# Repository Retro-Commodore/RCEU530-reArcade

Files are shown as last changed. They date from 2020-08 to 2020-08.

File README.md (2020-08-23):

# RCEU530-reArcade
 new Arcade PCB with autofire

reArcade is an all microswitch drop-in replacement PCB for the Arcade joystick.  
Added is the possibility of an autofire using a 555 timer.  
Microswtich in firebutton - in case you don't want to modify the original pcb.  

In order to use autofire, a new cable is required which supplies 5v.

The long arm microswitch needs to be bent 90deg, 1.6-1.7cm from where it enters the house, then +1cm from there approx 80deg. You may need to test it by trial-and-error.

# BOM
4x Microswitches with regular size arm [eBay](https://www.ebay.com/itm/10-X-KW4-3Z-3-Hinge-Roller-Lever-SPDT-Momentary-Micro-Limit-Switch-3D-printer/122688679006).  
1x Microswitch with long arm [eBay](https://www.ebay.com/itm/5Pcs-AC250-125V-5A-3P-Momentary-36mm-Lever-Arm-Micro-Switch-Green-KW12-9S/233272820914).  
1x 1x7 pin male pinheader.  
  
**Optional Autofire**  
1x on/off switch  
1x SMD 0805 Resistor 33k  
1x SMD 0805 Resistor 4k7  
2x SMD 0805 Capacitor 10nF  
1x SMD 555 timer  
1x Joystick cable with 5v (min 7 wire cable, DB9 female, 1x7 pin female connector 2.54mm - or just get a finished extension cable on ebay).  

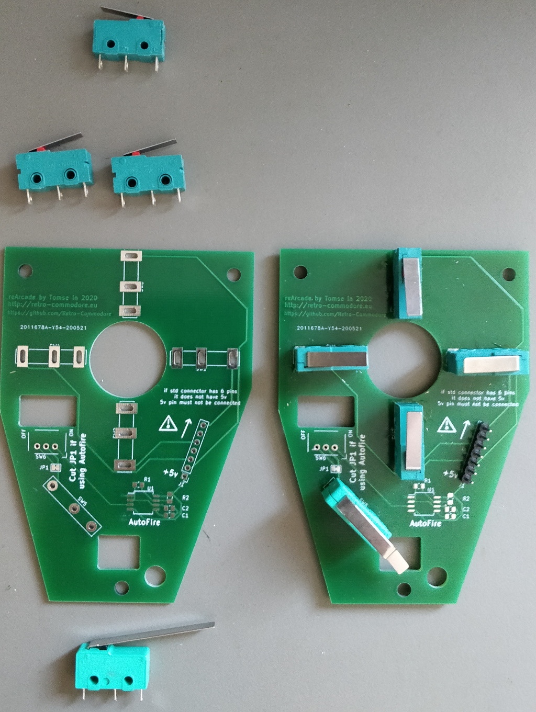
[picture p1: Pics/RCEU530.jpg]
Rendered Pic


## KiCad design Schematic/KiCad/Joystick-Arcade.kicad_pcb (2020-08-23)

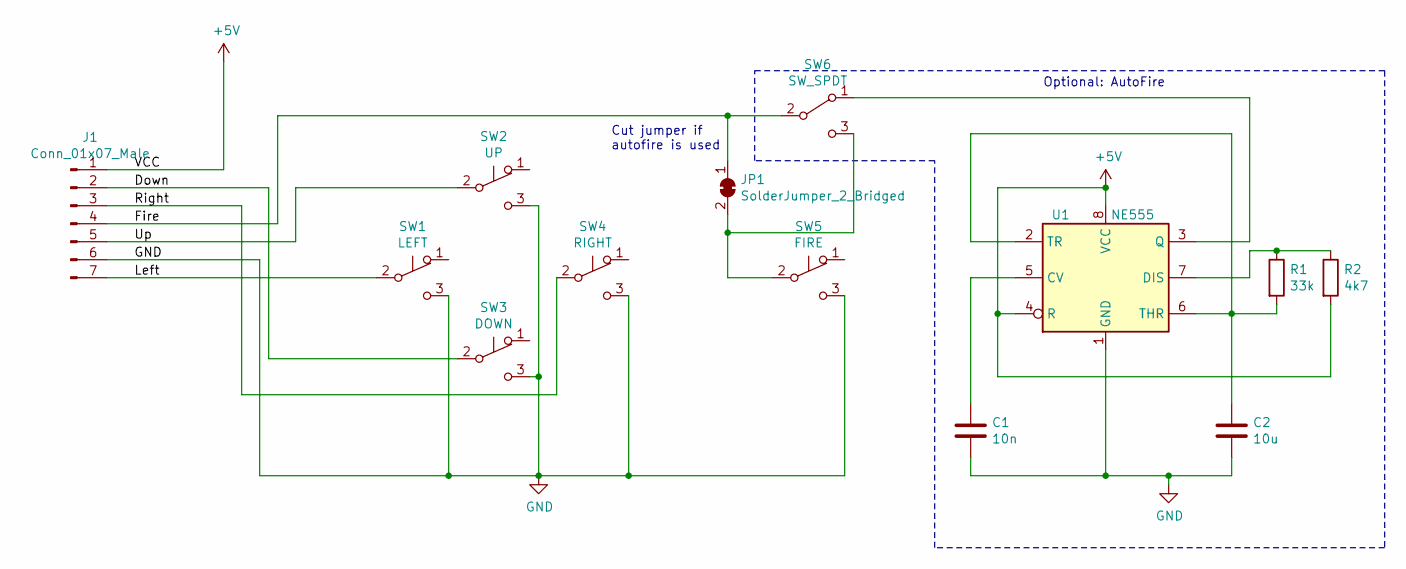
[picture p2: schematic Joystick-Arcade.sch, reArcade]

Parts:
C1: 10n; C_0805_2012Metric
C2: 10u; C_0805_2012Metric
J1: Conn_01x07_Male; PinHeader_1x07_P2.54mm_Vertical
JP1: SolderJumper_2_Bridged; SolderJumper-2_P1.3mm_Bridged_Pad1.0x1.5mm
R1: 33k; R_0805_2012Metric_Pad1.15x1.40mm_HandSolder
R2: 4k7; R_0805_2012Metric_Pad1.15x1.40mm_HandSolder
SW1: LEFT; Microswitch-no-nc-c-wire
SW2: UP; Microswitch-no-nc-c-wire
SW3: DOWN; Microswitch-no-nc-c-wire
SW4: RIGHT; Microswitch-no-nc-c-wire
SW5: FIRE; Microswitch-nc-no-c-pcb
SW6: SW_SPDT; SW_E-Switch_SS12D00G3_SPDT_Angled
U1: NE555; SO-8_5.3x6.2mm_Pitch1.27mm

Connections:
+5V: J1.1, R2.2, U1.4 (R), U1.8 (VCC)
/Down: J1.2, SW3.2 (B)
/Fire: J1.4, JP1.1 (A), SW6.2 (B)
/Left: J1.7, SW1.2 (B)
/Right: J1.3, SW4.2 (B)
/Up: J1.5, SW2.2 (B)
GND: C1.2, C2.2, J1.6, SW1.3 (C), SW2.3 (C), SW3.3 (C), SW4.3 (C), SW5.3 (C), U1.1 (GND)
unnamed: C1.1, U1.5 (CV)
unnamed: C2.1, R1.2, U1.2 (TR), U1.6 (THR)
unnamed: JP1.2 (B), SW5.2 (B), SW6.3 (C)
unnamed: R1.1, R2.1, U1.7 (DIS)
unnamed: SW6.1 (A), U1.3 (Q)

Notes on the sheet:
Optional: AutoFire
Cut jumper if autofire is used

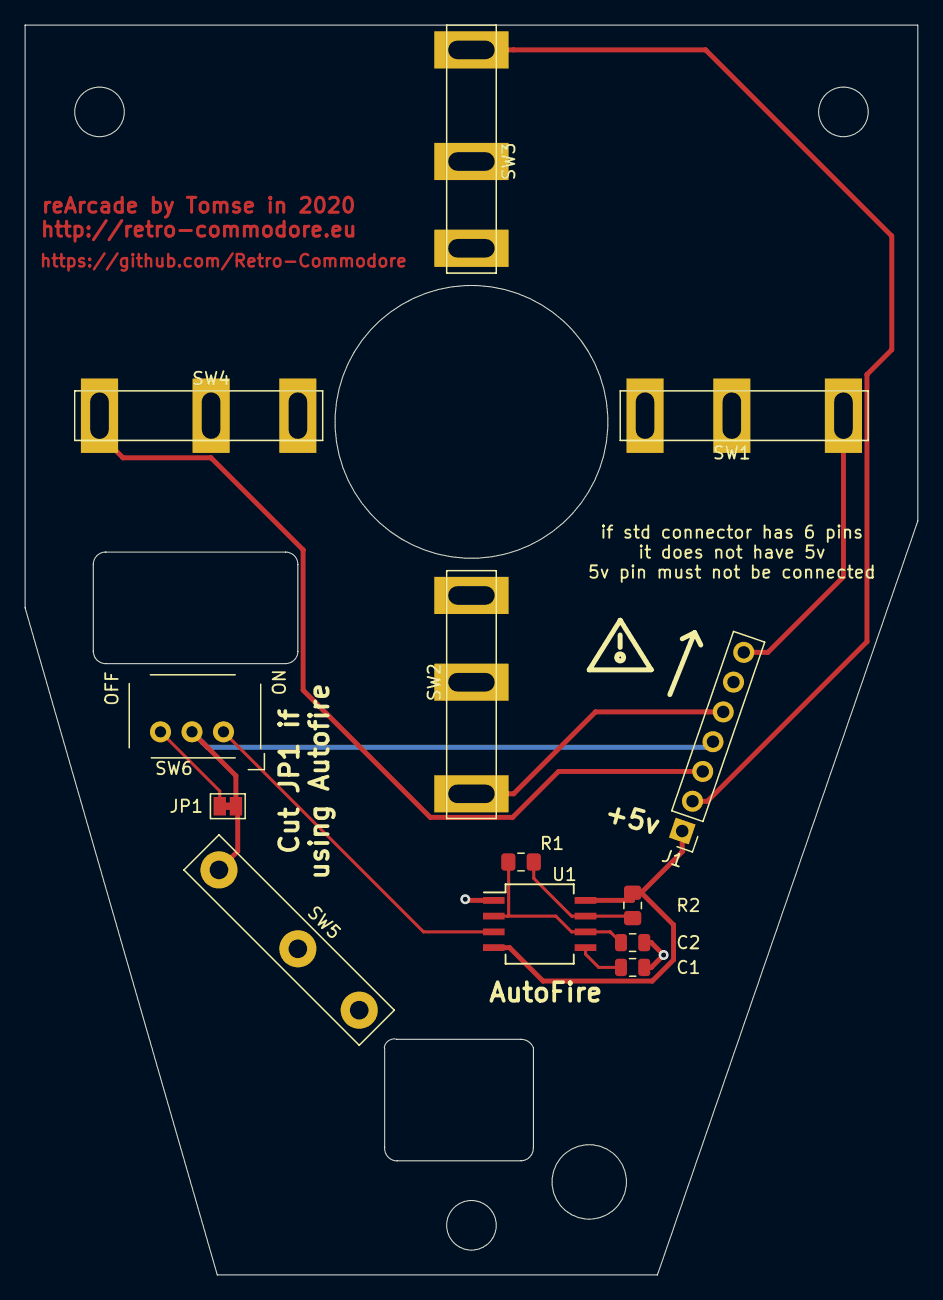
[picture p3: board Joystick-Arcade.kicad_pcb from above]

Board: 2 copper layers, 72.0 x 100.8 mm, 13 parts (0 on the bottom side), 12 nets.
